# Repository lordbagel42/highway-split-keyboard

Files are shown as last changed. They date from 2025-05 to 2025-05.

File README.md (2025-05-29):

# Turing Split - HIGHWAY

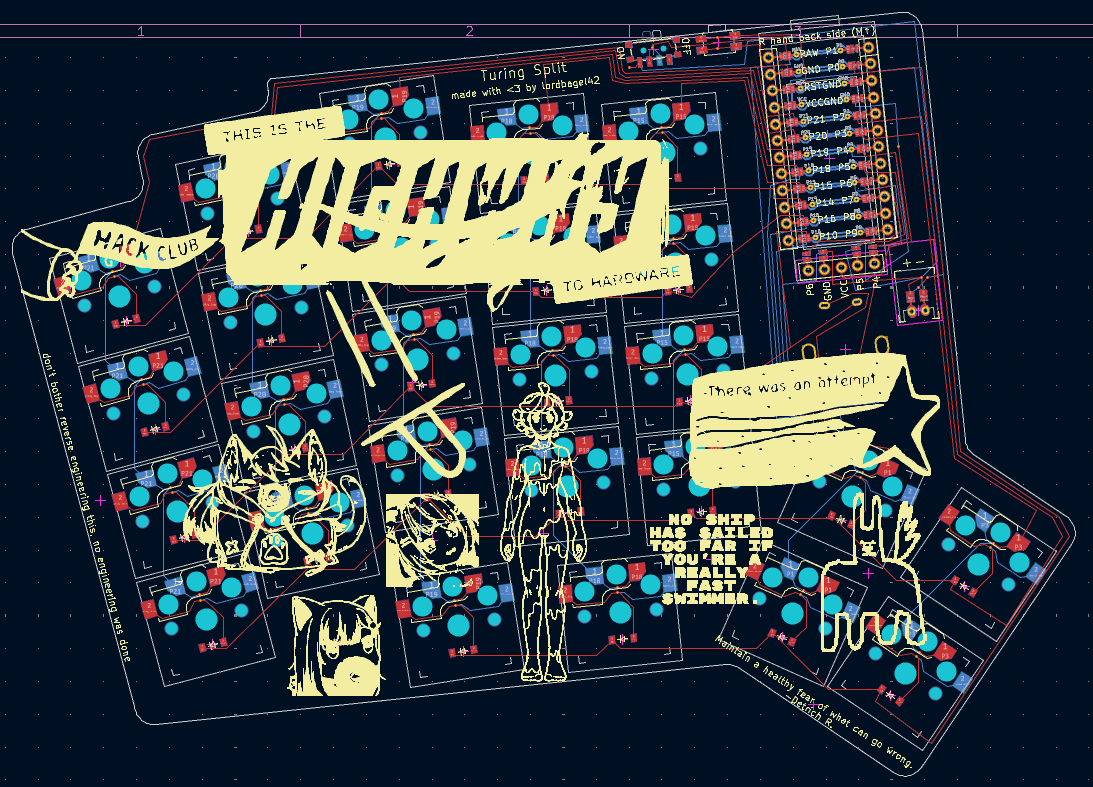
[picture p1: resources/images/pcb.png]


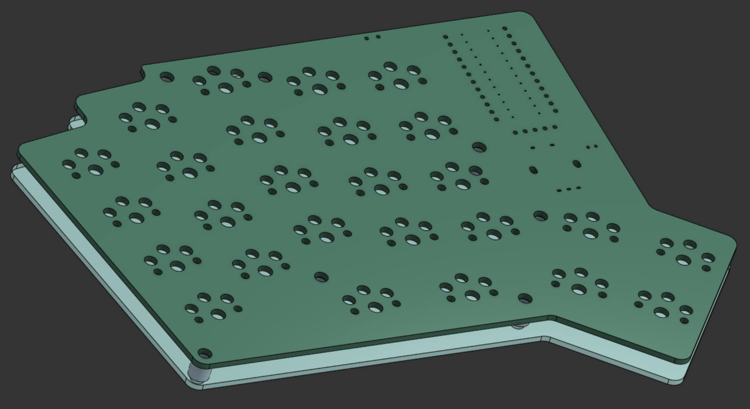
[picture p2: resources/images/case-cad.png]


<sub>this ^ will be replaced with a photo of the actual keyboard once it's built</sub>

## why?

I type a lot. Like, an insane amount. I write code for my robotics team and a lot for Hack Club, so I need a decent keyboard.
I've been using the Apple Magic Keyboard for a long while, and it's honestly quite nice. I originally bought it because my Quest 2 can track it.

However, I also am prone to carpal tunnel and other hand/fingie-issues, so I figured I should get a keyboard.
This led me to a discovery: Keyboards, are not cheap.

Then I discovered Highway and had a thought: make someone else pay for my keyboard.

## my keyboard design

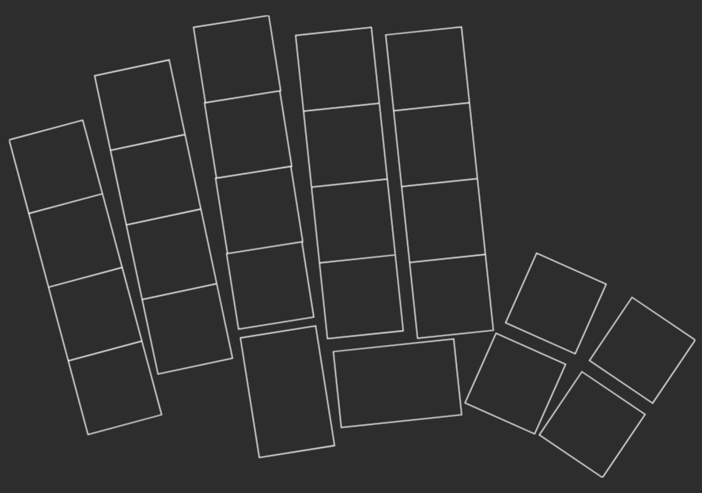
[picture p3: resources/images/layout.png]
the layout


I was tempted to go all out and build a full desk size keyboard contraption, but then I found [ergogen](https://ergogen.ceoloide.com/?exp=kicanvas) and decided to make an ergonomic, split-deck keyboard.
I based this off of a lot of random keyboards I saw throughout the internet and had one main focus when designing: comfortable, but not confusing.

I like layers. I plan to use them. I also want to have enough buttons I can do things easily and without thinking. If I wanted chords, I would have made a stenography keyboard.

This isn't the most complicated design, it's not the most simple, but it is mine, and I feel happy with it.

## the bom

Overall, the cost comes out to about $180 w/ tax.

| ITEM | SUPPLIER | COUNT | UNIT COST | ROW COST | LOW BUDGET USE | HIGH BUDGET USE |
| --- | --- | ----- | --- | --- | --- | --- |
| nice!nano v2 | typeractive.xyz | 1 | $25.00 | $25.00 | 17% | 7% |
| nice!view | typeractive.xyz | 1 | $20.00 | $20.00 | 13% | 6% |
| PCB | JLCPCB | 1 | $12.00 | $12.00 | 8% | 3% |
| PCB Shipping | JLCPCB | 1 | $25.00 | $25.00 | 17% | 7% |
| Kailh Hotswap Sockets | typeractive.xyz | 60 | $0.15 | $9.00 | 6% | 3% |
| Battery Jack | typeractive.xyz | 2 | $0.50 | $1.00 | 1% | 0% |
| 1.5u Keycap | typeractive.xyz | 4 | $0.50 | $2.00 | 1% | 1% |
| Homing Keycap | typeractive.xyz | 2 | $0.50 | $1.00 | 1% | 0% |
| Keycap | typeractive.xyz | 50 | $0.40 | $20.00 | 13% | 6% |
| Choc Switches | typeractive.xyz | 60 | $0.55 | $33.00 | 22% | 9% |
| Diodes | typeractive.xyz | 60 | $0.08 | $4.50 | 3% | 1% |
| Power Switch | typeractive.xyz | 2 | $0.75 | $1.50 | 1% | 0% |
| Sockets and Pins | typeractive.xyz | 2 | $6.50 | $13.00 | 9% | 4% |
| Encoder | aliexpress | 2 | $1.10 | $2.20 | 1% | 1% |

## notes

Something to note about this is a bit of a habit I've picked up from my apple keyboard: I don't like thick keyboards. My magic keyboard is maybe 7 millimeters tall at maximum and about 3 at the minimum. I am okay with something a bit thicker, but I don't want something as thick as a normal keyboard.

This is also part of why I went for low profile keys and keycaps, hence the Choc switches instead of the more common MX switches.

I also don't want a case to help with that. Because of the requirements for Highway, I have one. It's a very thin case designed to be lasercut using acrylic and 3d printed standoffs.

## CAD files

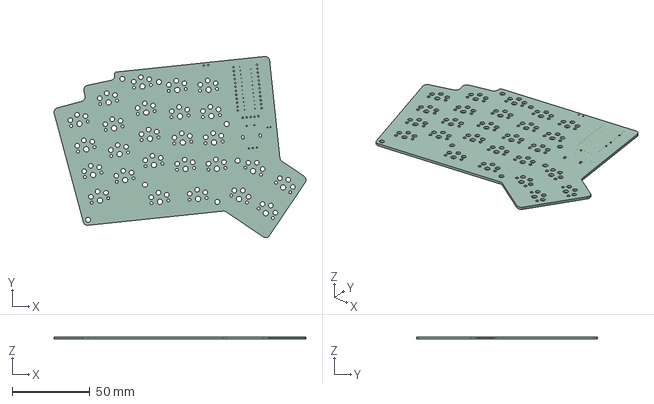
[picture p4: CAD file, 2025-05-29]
og-pcb.step
161.9 x 116.3 x 1.51 mm

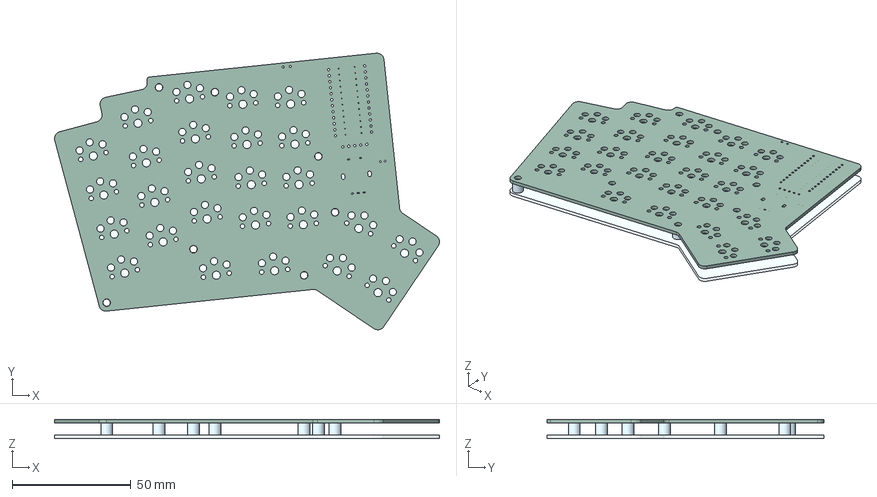
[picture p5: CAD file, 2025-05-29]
turing-split.step
161.9 x 116.3 x 8.02 mm
standoff x 7
acrylic
keeb_PCB

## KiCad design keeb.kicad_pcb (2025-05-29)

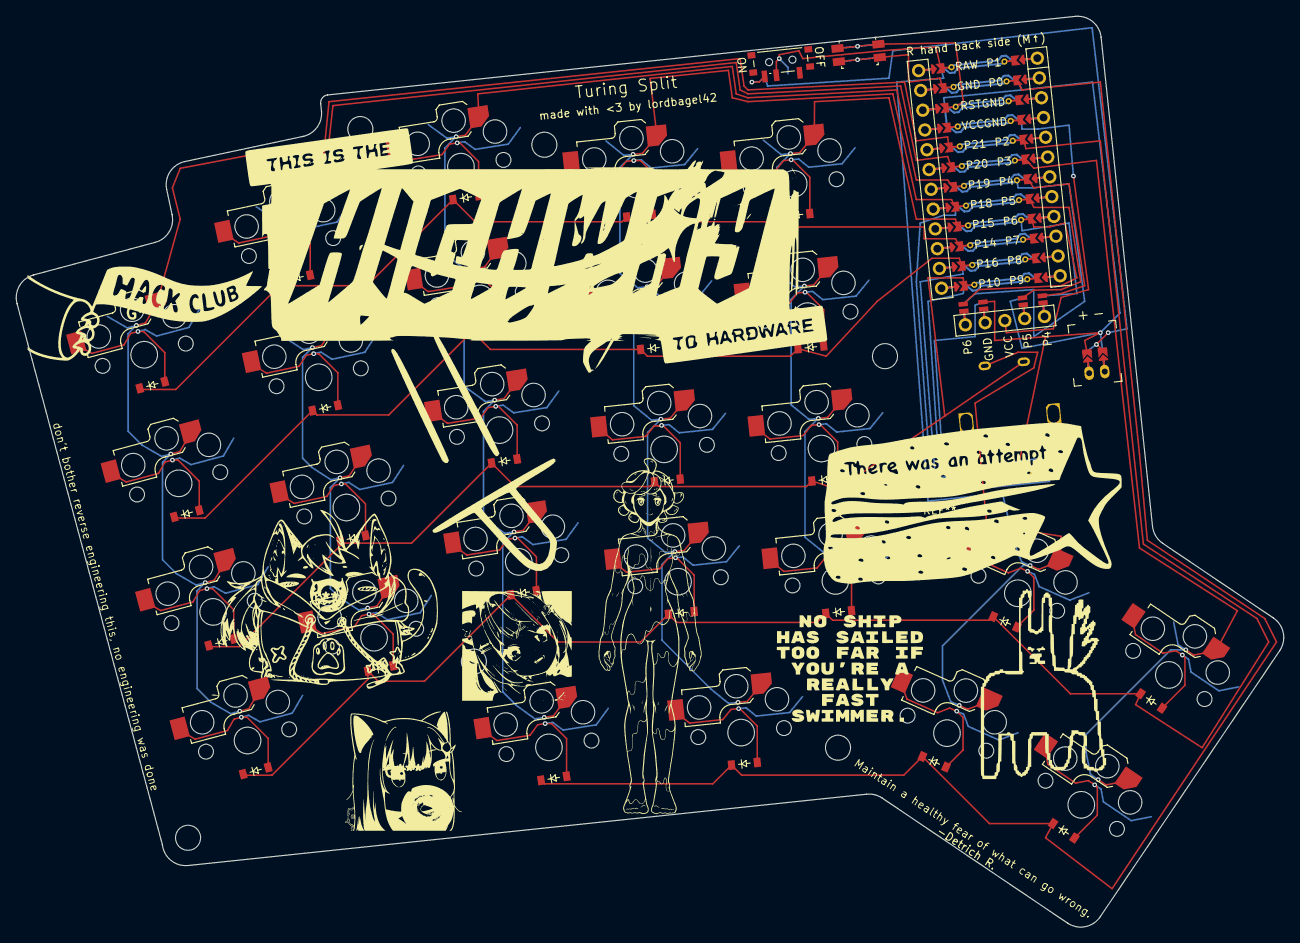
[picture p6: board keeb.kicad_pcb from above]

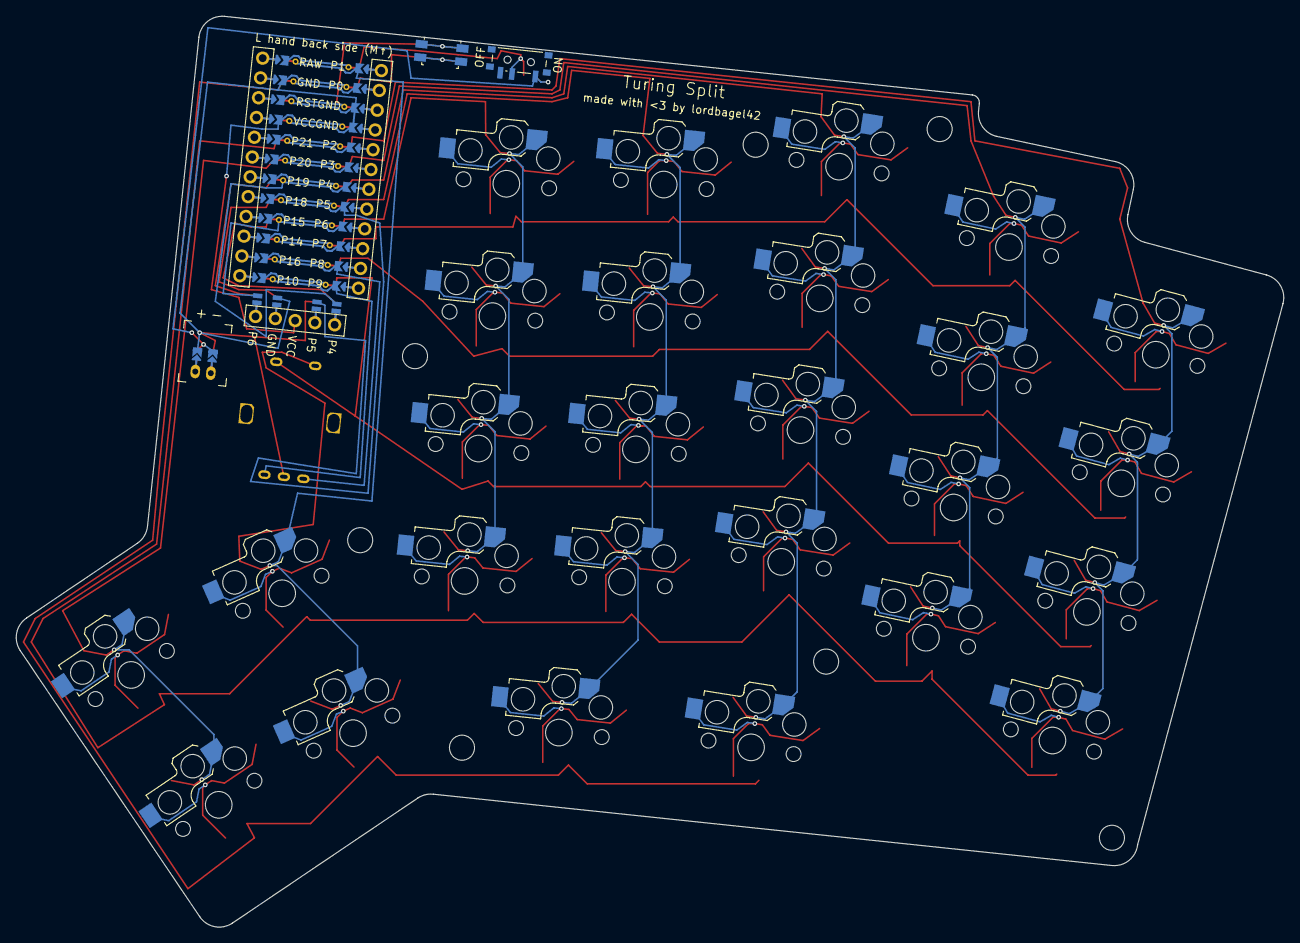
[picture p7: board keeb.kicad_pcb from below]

Board: 2 copper layers, 161.9 x 116.3 mm, 60 parts (27 on the bottom side), 54 nets.

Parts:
D1, D2, D3, D4, D5, D6, D7, D8, D9, D10, D11, D12, D13, D14, D15, D16, D17, D18, D19, D20, D21, D22, D23, D24, D25, D26: diode_tht_sod123
DISP1: display_nice_view
JST1: battery_connector_jst_ph_2
MCU1: mcu_nice_nano
Maintain a healthy fear of what can go wrong.: -Detrich R.; maintainfear
PWR1: power_switch_smd_side
RE1: rotary_encoder_ec11_ec12
RST1: reset_switch_smd_side
S1, S2, S3, S4, S5, S6, S7, S8, S9, S10, S11, S12, S13, S14, S15, S16, S17, S18, S19, S20, S21, S22, S23, S24, S25, S26: switch_choc_v1_v2
don't bother reverse engineering this, no engineering was done: Untitled

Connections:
BAT_P: JST1.1, PWR1.1, PWR1.3
DISP1_1: DISP1.1, DISP1.10, DISP1.23
DISP1_2: DISP1.2, DISP1.11, DISP1.22
DISP1_4: DISP1.4, DISP1.12, DISP1.21
DISP1_5: DISP1.5, DISP1.13, DISP1.20
GND: DISP1.15, DISP1.25, JST1.2, MCU1.103, MCU1.104, MCU1.123, RE1.B, RST1.2, RST1.4
JST1_1: JST1.11, JST1.21, JST1.31
JST1_2: JST1.12, JST1.22, JST1.32
P0: D13.1, D22.1, D24.1, D26.1, MCU1.102
P1: MCU1.101, RE1.S1, S23.1, S24.1
P2: D1.1, D5.1, D9.1, D14.1, D18.1, D23.1, D25.1, MCU1.105
P3: MCU1.106, S25.1, S26.1
P4: DISP1.17, DISP1.27, MCU1.107
P5: DISP1.16, DISP1.26, MCU1.108
P6: DISP1.14, DISP1.24, MCU1.109
P8: MCU1.111, RE1.C
P9: MCU1.112, RE1.A
P10: D2.1, D6.1, D10.1, D15.1, D19.1, MCU1.113, RE1.S2
P14: D4.1, D8.1, D12.1, D17.1, D21.1, MCU1.115
P15: MCU1.116, S18.1, S19.1, S20.1, S21.1
P16: D3.1, D7.1, D11.1, D16.1, D20.1, MCU1.114
P18: MCU1.117, S14.1, S15.1, S16.1, S17.1, S22.1
P19: MCU1.118, S9.1, S10.1, S11.1, S12.1, S13.1
P20: MCU1.119, S5.1, S6.1, S7.1, S8.1
P21: MCU1.120, S1.1, S2.1, S3.1, S4.1
RAW: MCU1.124, PWR1.2
RST: MCU1.122, RST1.1, RST1.3
VCC: DISP1.3, MCU1.121
first_bottom: D24.2, S24.2
first_top: D23.2, S23.2
index_bottom: D14.2, S14.2
index_home: D15.2, S15.2
index_number: D17.2, S17.2
index_top: D16.2, S16.2
inner_bottom: D18.2, S18.2
inner_home: D19.2, S19.2
inner_number: D21.2, S21.2
inner_top: D20.2, S20.2
middle_additional: D13.2, S13.2
middle_bottom: D9.2, S9.2
middle_home: D10.2, S10.2
middle_number: D12.2, S12.2
middle_top: D11.2, S11.2
pinky_bottom: D1.2, S1.2
pinky_home: D2.2, S2.2
pinky_number: D4.2, S4.2
pinky_top: D3.2, S3.2
ring_bottom: D5.2, S5.2
ring_home: D6.2, S6.2
ring_number: D8.2, S8.2
ring_top: D7.2, S7.2
second_bottom: D26.2, S26.2
second_top: D25.2, S25.2
space_top: D22.2, S22.2

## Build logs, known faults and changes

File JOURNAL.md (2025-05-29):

---
title: "Simple Split Keyb (NAME CHANGE NEEDED)"
author: "Raygen Rupe"
description: "its a simple ergonomic split deck keyboard for a large handed individual"
created_at: "2025-05-23"
---

## total hour count: about 20

# May 23: The Beginning

I've decided to make a custom split-deck keyboard because I have large hands and my current keyboard doesn't really work well for long programming sessions.

I'm using a software called Ergogen to help design the keyboard because its effectively parametric (and I don't know enough about pcb design to do it fully in kicad lol).

It's going good.

As of 2:33 pm, time spent is 4 hours.

## this is taking a while

It's now 10:35 PM. I've gotten the layout to a point I'm actually really happy with. The wiring is sketchy as all hell and this is one of the most confusing things I've ever drawn.

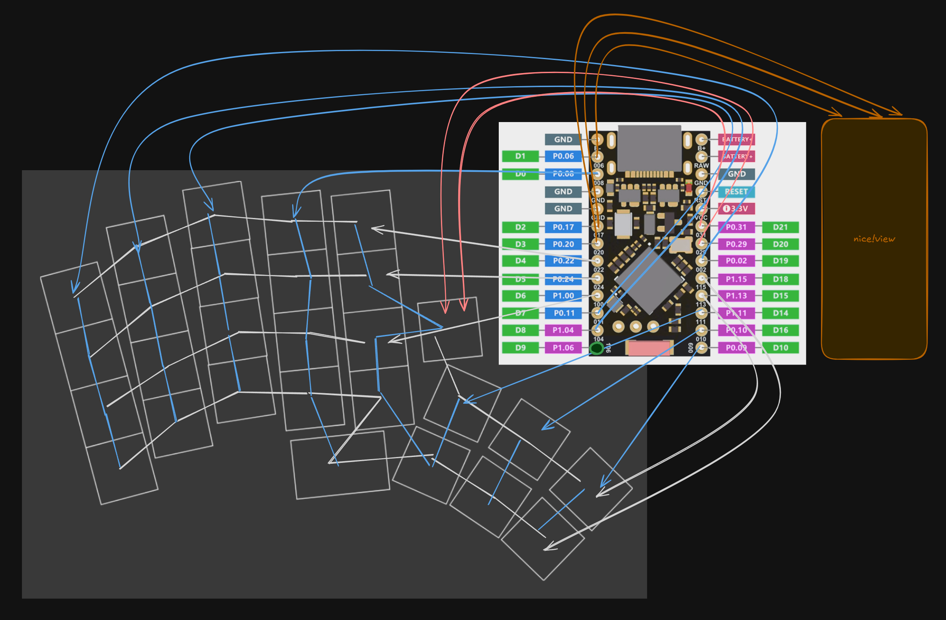
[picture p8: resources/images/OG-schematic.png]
the og schematic


## this took quite a while

its 11:24 PM. I've added a battery connector, power switch, and reset button. Still need to route the whole thing and do the CAD for the case.

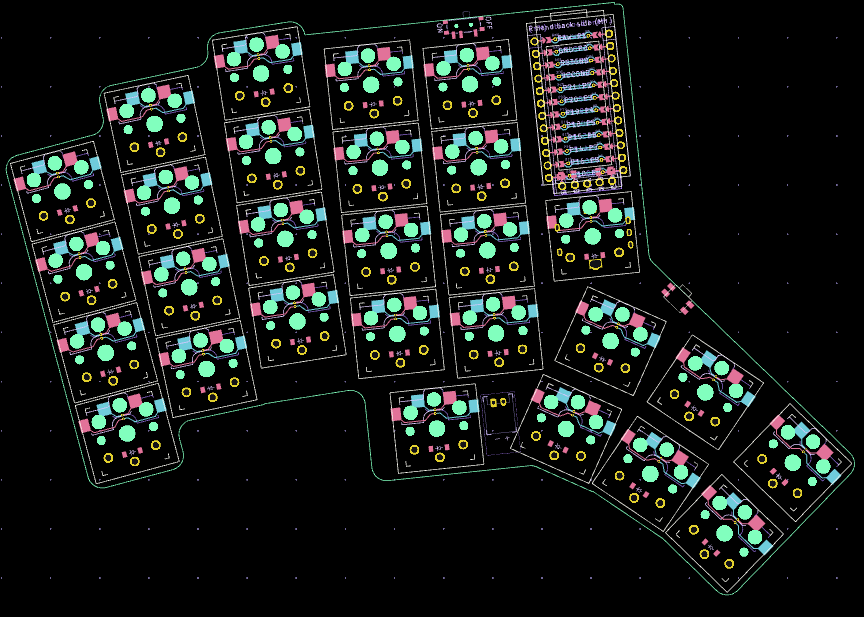
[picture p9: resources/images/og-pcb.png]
the og pcb


but it looks sick!

# May 25: It Continues.

So turns out I accidentally did something wrong and direct-wired my ground pin. It's why freerouting was absolutely dying when I tried to use it lol.

Fixing that, then have to work on the pcb.
time: 6:46 AM

# May 27: Finished!

time: 5:24 AM

I had a migraine since my last journal entry, so I had to take a break for a while.

Today I spent most of my time routing the PCB. I redid my "schematic" in Excalidraw and came up with this:

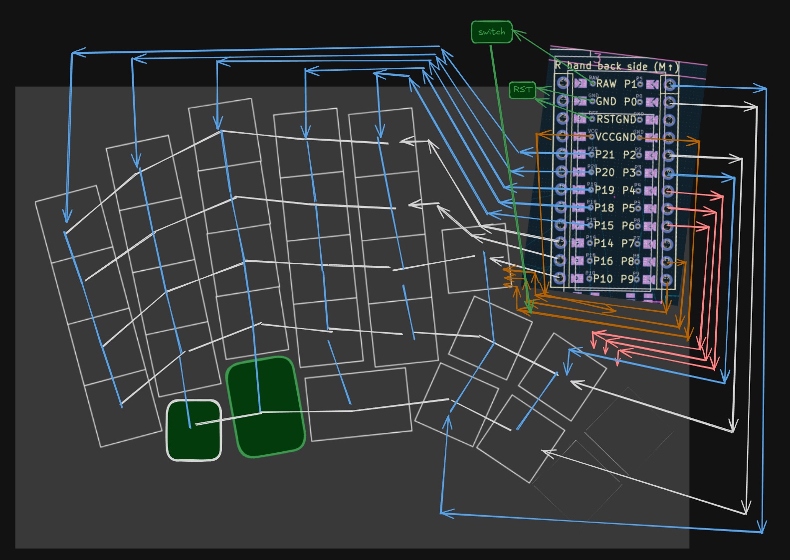
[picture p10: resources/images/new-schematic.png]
new schematic


Still doesn't make any sense, but I could at least follow it enough to make the PCB itself. And redo the configuration files.

Overall, I'm pretty proud of how the PCB came out. It's fully reversible and while I did mess up and have to re-route the entire thing, it came out well.

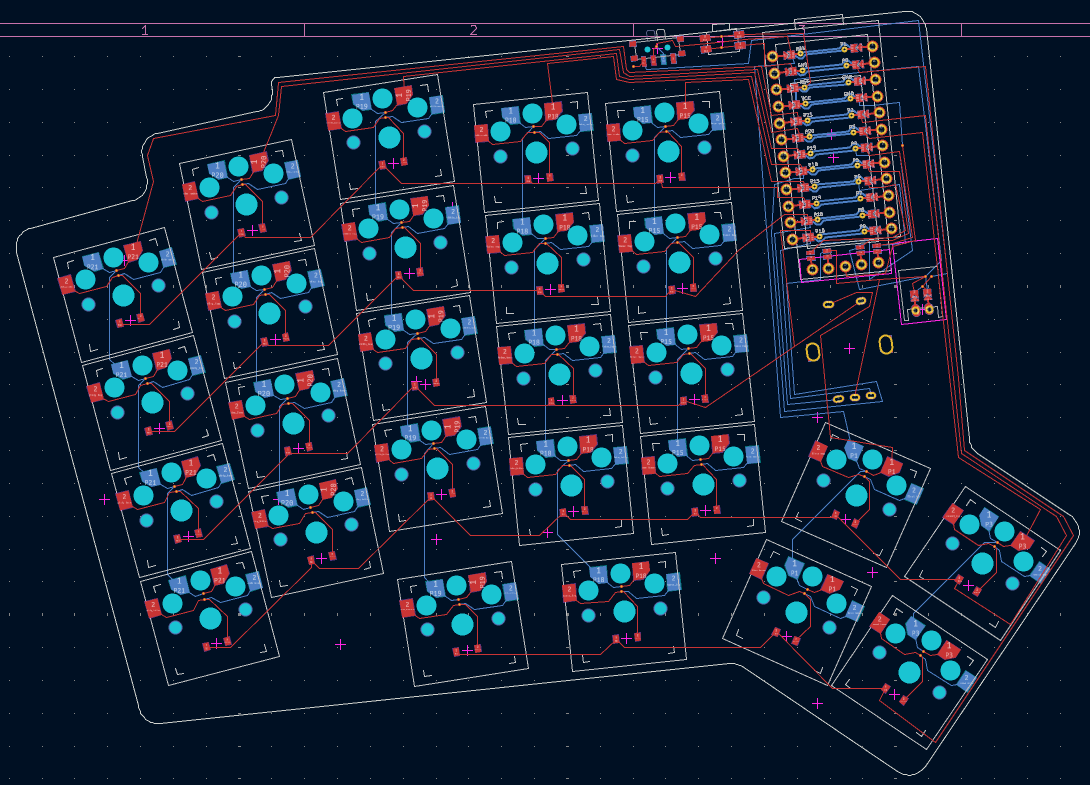
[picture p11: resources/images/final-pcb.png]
the final pcb


I also coated it in silkscreen art, that was fun.

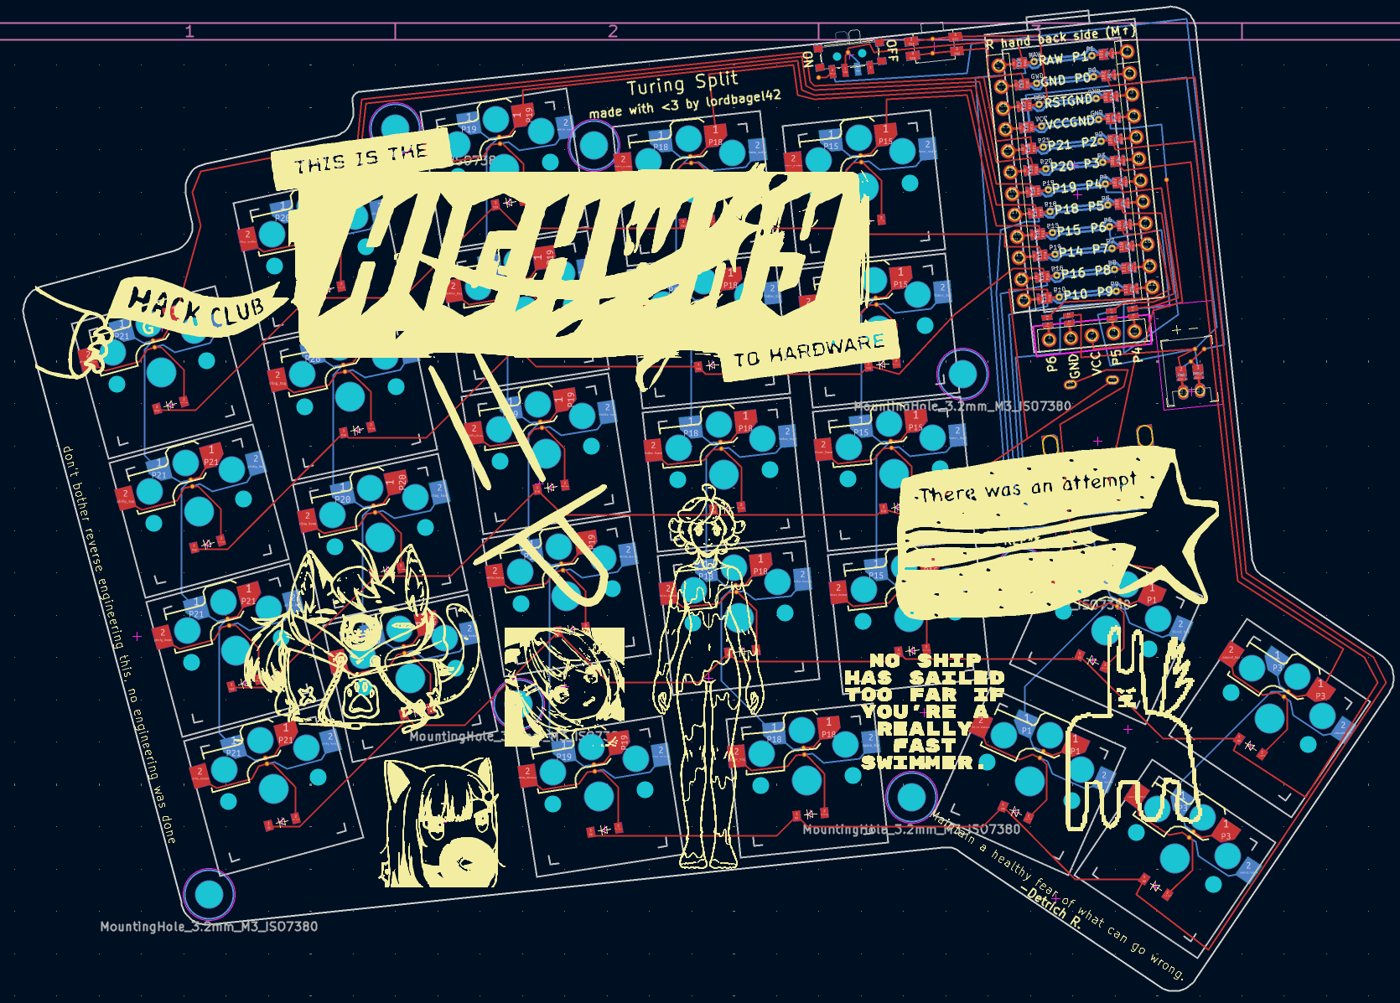
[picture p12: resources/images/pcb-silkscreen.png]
the pcb with silkscreen


Thanks for reading

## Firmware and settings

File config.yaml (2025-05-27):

meta:
  engine: 4.1.0

units:
  # Proxy Spacing Variables
  kx: cx
  ky: cy
  # Padding Variables
  px: kx + 2
  py: ky + 2
  $default_width: 17
  $default_height: 17

points:
  zones:
    matrix:
      anchor.shift: [50,-100] # Fix KiCad placement
      columns:
        pinky:
          key:
            # valid
            column_net: P21
            spread: 1kx
            splay: 15
            origin: [0, -17]
          rows:
            bottom:
              bind: [5, 1, 1, 5]
            home:
              bind: [1, 10, 1, 5]
            top:
              bind: [1, 8, 5, 5] 
            number:
              bind: [5, 10, 1, 5]
        ring:
          key:
            # valid
            column_net: P20
            spread: 19
            stagger: 17/2
            splay: -3
          rows:
            bottom:
              bind: [1, 1, 1, 10]
            home:
              bind: [5, 1, 5, 1]
            top:
              bind: [1, 6, 1, 1]
            number:
              bind: [5, 10, 10, 5]

        middle:
          key:
            # valid
            column_net: P19
            shift: [0.2, 0]
            spread: 19
            stagger: 17/3
            splay: -3
            origin: [0, -17]
          rows:
            additional:
              shift: [-0.5, -92]
              height: 27
              row_net: P0
              bind: [1, 5, 0, 1]
            bottom:
              bind: [1, 10, 7, 5]
            home:
              bind: 5
            top:
              bind: [1, 1, 1, 1]
            number:
              bind: [1, 1, 1, 1]

        index:
          key:
            # valid
            column_net: P18
            spread: 19
            stagger: -17/3
            splay: -3
            origin: [0, -17]
          rows:
            bottom:
              bind: [1, 5, 1, 1]
            home:
              bind: [5, 1, 5, 1]
            top:
              bind: [1, 1, 1, 6]
            number:
              bind: [6.5, 0, 10, 25]

        inner:
          key:
            # valid
            column_net: P15
            spread: 20
            stagger: -2
            origin: [0, -17]
          rows: 
            bottom:
              bind: [5, 20, 1, 2]
            home:
              bind: [17, 20, 1, 5]
            top:
              bind: [1, 1, 5, 5]
            number: 
              bind: [9, 32, 45, 50]
      rows:
        bottom:
          padding: 1ky
          # valid
          row_net: P2
        home:
          padding: 1ky
          # valid
          row_net: P10
        top:
          padding: 1ky
          # valid
          row_net: P16
        number:
          padding: 1ky
          # valid
          row_net: P14

    thumb:
      anchor:
        ref: matrix_inner_bottom
        shift: [4, -4]

      columns:
        space:
          key:
          rows:
            top:
              # valid
              row_net: P0
              # valid
              column_net: P18
              bind: [10, 15, 1, 66]
              shift: [-18, -14]
              rotate: 0
              width: 27
          rows.bottom.skip: true

        first:
          key:
            # valid
            column_net: P1
            splay: -30
          rows:
            top:
              padding: -20
              bind: [1, 1, 5, 70]
            bottom:
              shift: [-1, 0]
              bind: [1, 1, 1, 1]

        second:
          key:
            # valid
            column_net: P3
            origin: [-3, -12]
            splay: -10
            spread: 20
          rows:
            top:
              padding: -20
              shift: [0, -1]
              bind: [5, 1, 10, 50]
            bottom:
              shift: [0, 0]
              bind: [1, 1, 5, 15]

        # third:
        #   key:
        #     column_net: P10
        #     spread: 20
        #     splay: -10
        #     origin: [-9, -12]
        #   rows:
        #     top:
        #       padding: -20
        #       shift: [1, -1]
        #       bind: [1, 1, 10, 50]
        #     bottom:
        #       shift: [0, 0]
        #       bind: [1, 1, 1, 1]

      rows:
        top:
          padding: 17
          row_net: P2
        bottom:
          row_net: P0

      key:
        footprints:

    # rotary:
    #   anchor: thumb_first_top
    #   key:
    #     shift: [-12, 18]
    #     rotate: 30
    #     bind: [38, 2, 1, 2]
    #     # skip: true

  # mirror:
  #   ref: thumb_third_top
  #   distance: 50

outlines:
  _raw:
    - what: rectangle
      where: true
      bound: true
      asym: left
      size: [18,17]
      corner: 0
  _first:
    - what: outline
      name: _raw
      fillet: 3
  _second:
    - what: outline
      name: _first
      fillet: 2
  _third:
    - what: outline
      name: _second
      fillet: 1
  panel:
    - what: outline
      name: _third
      fillet: 0.5
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

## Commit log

2025-05-27 add the keyboard
    [keeb.kicad_pcb]
2025-05-29 remove exccess gerber files
    [keeb-B_Cu.gbr, keeb-B_Mask.gbr, keeb-B_Paste.gbr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]
2025-05-29 add BOM
2025-05-29 add mounting holes
    [keeb.kicad_pcb]
